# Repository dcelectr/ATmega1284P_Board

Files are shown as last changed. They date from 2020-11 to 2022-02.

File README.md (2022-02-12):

# ATmega1284P_Board
ATmega1284P board design is based on the [MightyCore](https://github.com/MCUdude/MightyCore).

The board features fairly easy to hand solder components, such as 0805 resistors, capacitors and LEDs, and it is breadboard friendly (100 mil spacing pin headers) with an orderly pin arrangement [(0 to 23, and A0 to A7)](https://camo.githubusercontent.com/318afd7cb36e720ea851fb34409d54c36701d0300eade1ba0faea744f00fc5db/68747470733a2f2f692e696d6775722e636f6d2f4b3334785a62342e6a7067) of the TQFP-44 package. 

The programming connector is a standard FTDI USB-UART adapter pin-out. The solder jumper (JP1) is closed by default. The board can be powered from the breadboard pin headers or the FTDI programming header. Using an FTDI TTL-232RG-VIP USB-UART adapter, the TTL voltage (Vttl) would be the same as the Vcc.

The Bill of Materials is also included (see file ATmega1284P.csv).

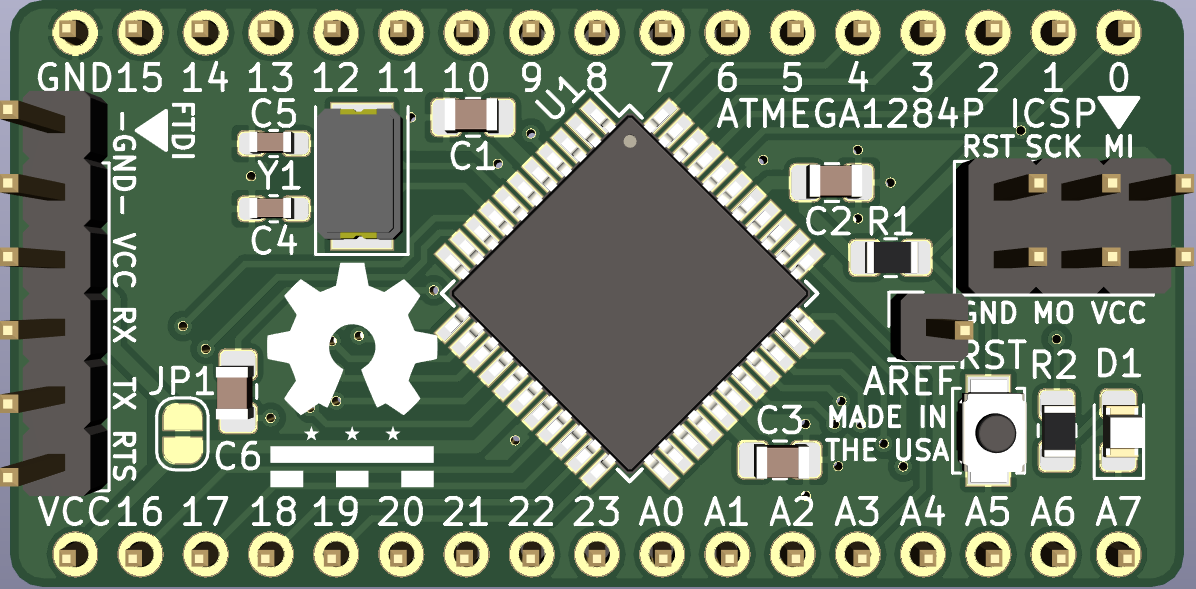
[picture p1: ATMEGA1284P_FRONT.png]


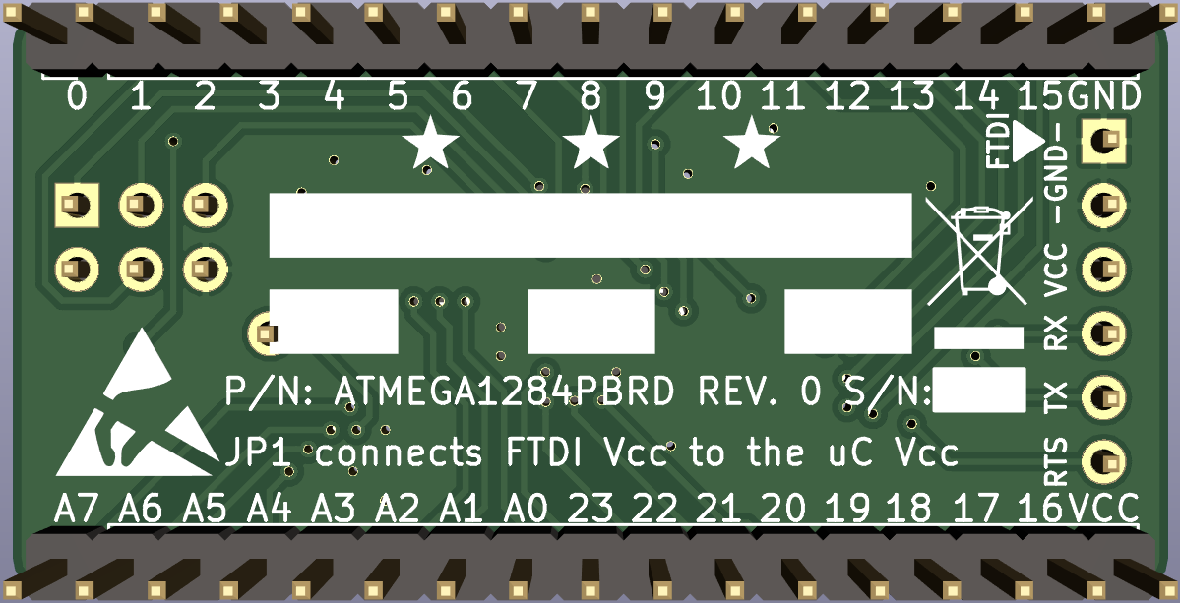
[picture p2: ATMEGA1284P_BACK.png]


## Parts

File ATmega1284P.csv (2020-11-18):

Reference | Quantity | Value | Footprint | Datasheet | P/N
C1 C2 C3 C6 | 4 | 0.1uF | Capacitor_SMD:C_0805_2012Metric_Pad1.18x1.45mm_HandSolder | ~ | C0805C104M3RACTU
C4 C5 | 2 | 22pF | Capacitor_SMD:C_0603_1608Metric_Pad1.08x0.95mm_HandSolder | ~ | C0603C220K3GACTU
D1 | 1 | LED | LED_SMD:LED_0805_2012Metric_Pad1.15x1.40mm_HandSolder | ~ | 150080VS75000
J1 | 1 | Conn_02x03_Odd_Even | Connector_PinHeader_2.54mm:PinHeader_2x03_P2.54mm_Vertical | ~
J2 | 1 | Conn_01x06_Male | Connector_PinHeader_2.54mm:PinHeader_1x06_P2.54mm_Vertical | ~
J3 J4 | 2 | Conn_01x17_Male | Connector_PinHeader_2.54mm:PinHeader_1x17_P2.54mm_Vertical | ~
J5 | 1 | Conn_01x01_Male | Connector_PinHeader_2.54mm:PinHeader_1x01_P2.54mm_Vertical | ~
JP1 | 1 | SolderJumper_2_Bridged | Jumper:SolderJumper-2_P1.3mm_Bridged_RoundedPad1.0x1.5mm | ~
R1 | 1 | 10K | Resistor_SMD:R_0805_2012Metric_Pad1.20x1.40mm_HandSolder | ~ | ERJ-6GEYJ103V
R2 | 1 | 1K | Resistor_SMD:R_0805_2012Metric_Pad1.20x1.40mm_HandSolder | ~ | ERJ-6GEYJ102V
SW1 | 1 | SW_Push | Button_Switch_SMD:SW_SPST_B3U-1000P | ~ | B3U-1000P
U1 | 1 | ATmega1284P-A | Package_QFP:TQFP-44_10x10mm_P0.8mm | http://ww1.microchip.com/downloads/en/DeviceDoc/Atmel-8272-8-bit-AVR-microcontroller-ATmega164A_PA-324A_PA-644A_PA-1284_P_datasheet.pdf | ATMEGA1284P-AU
Y1 | 1 | 16MHz | Crystal:Crystal_SMD_5032-2Pin_5.0x3.2mm | ~ | 7A-16.000MAAE-T

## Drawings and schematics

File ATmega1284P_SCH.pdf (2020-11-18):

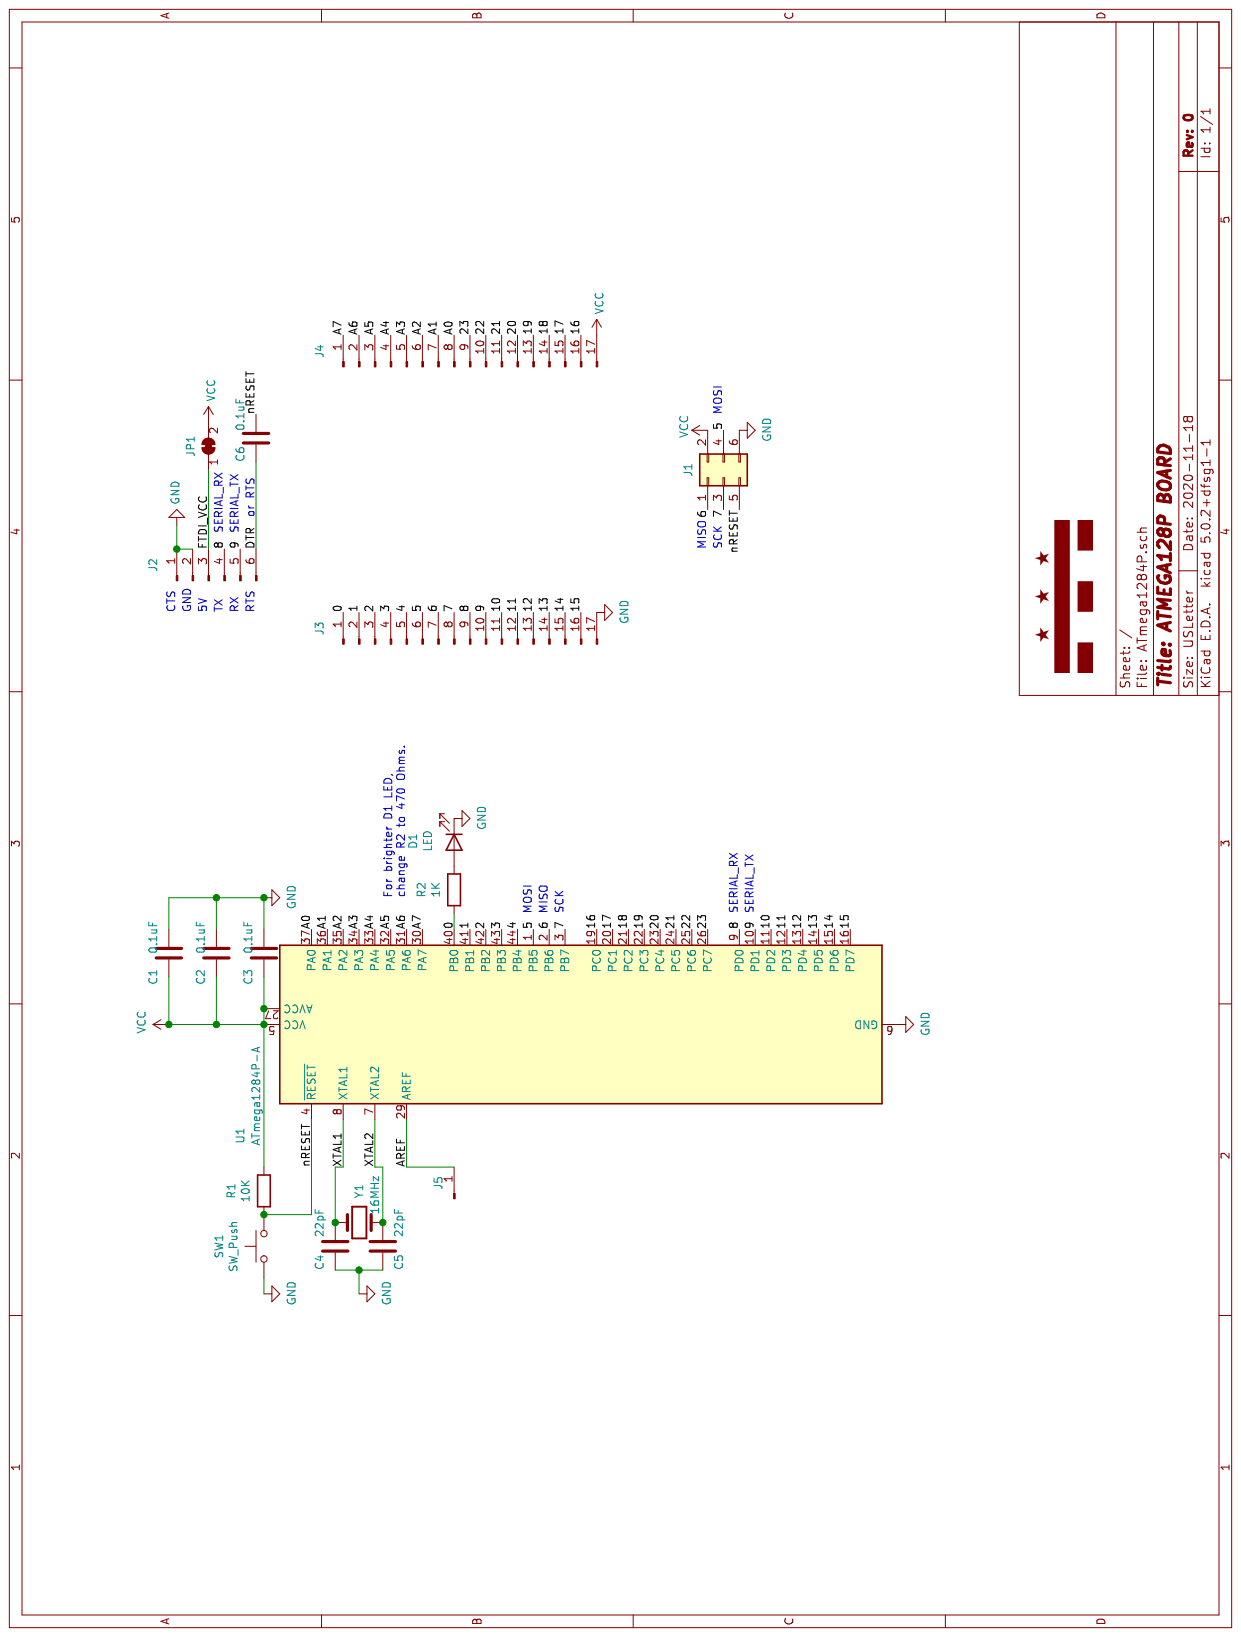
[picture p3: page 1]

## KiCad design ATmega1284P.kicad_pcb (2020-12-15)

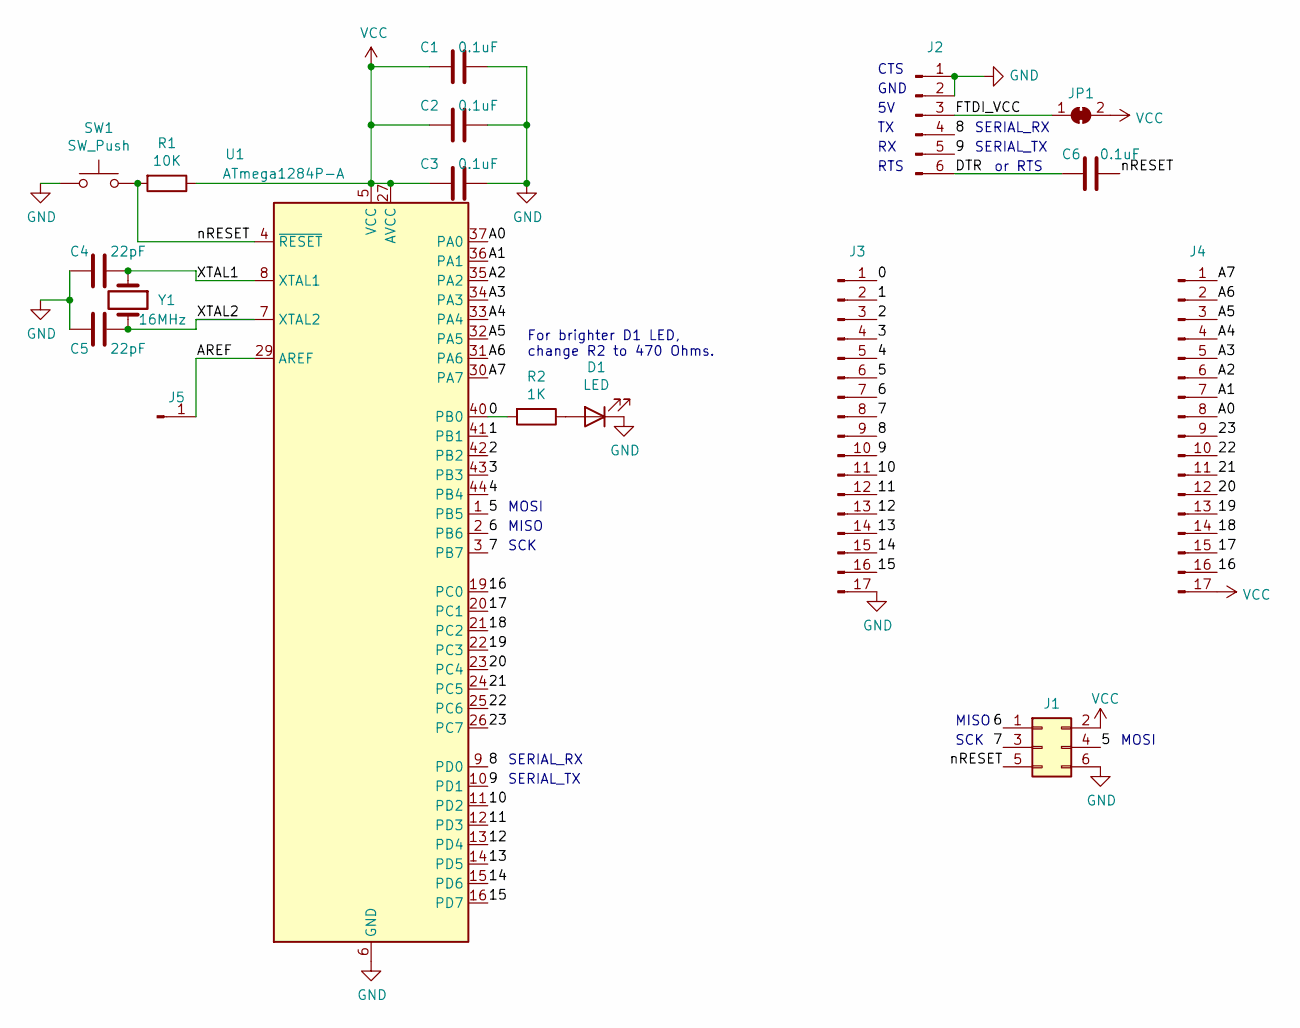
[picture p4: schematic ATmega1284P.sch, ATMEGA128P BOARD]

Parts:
C1, C2, C3, C6: 0.1uF; C_0805_2012Metric_Pad1.18x1.45mm_HandSolder
C4, C5: 22pF; C_0603_1608Metric_Pad1.08x0.95mm_HandSolder
D1: LED; LED_0805_2012Metric_Pad1.15x1.40mm_HandSolder
J1: Conn_02x03_Odd_Even; PinHeader_2x03_P2.54mm_Vertical
J2: Conn_01x06_Male; PinHeader_1x06_P2.54mm_Vertical
J3, J4: Conn_01x17_Male; PinHeader_1x17_P2.54mm_Vertical
J5: Conn_01x01_Male; PinHeader_1x01_P2.54mm_Vertical
JP1: SolderJumper_2_Bridged; SolderJumper-2_P1.3mm_Bridged_RoundedPad1.0x1.5mm
R1: 10K; R_0805_2012Metric_Pad1.20x1.40mm_HandSolder
R2: 1K; R_0805_2012Metric_Pad1.20x1.40mm_HandSolder
SW1: SW_Push; SW_SPST_B3U-1000P
U1: ATmega1284P-A; TQFP-44_10x10mm_P0.8mm
Y1: 16MHz; Crystal_SMD_5032-2Pin_5.0x3.2mm

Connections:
/0: J3.1, R2.2, U1.40 (PB0)
/1: J3.2, U1.41 (PB1)
/2: J3.3, U1.42 (PB2)
/3: J3.4, U1.43 (PB3)
/4: J3.5, U1.44 (PB4)
/5: J1.4, J3.6, U1.1 (PB5)
/6: J1.1, J3.7, U1.2 (PB6)
/7: J1.3, J3.8, U1.3 (PB7)
/8: J2.4, J3.9, U1.9 (PD0)
/9: J2.5, J3.10, U1.10 (PD1)
/10: J3.11, U1.11 (PD2)
/11: J3.12, U1.12 (PD3)
/12: J3.13, U1.13 (PD4)
/13: J3.14, U1.14 (PD5)
/14: J3.15, U1.15 (PD6)
/15: J3.16, U1.16 (PD7)
/16: J4.16, U1.19 (PC0)
/17: J4.15, U1.20 (PC1)
/18: J4.14, U1.21 (PC2)
/19: J4.13, U1.22 (PC3)
/20: J4.12, U1.23 (PC4)
/21: J4.11, U1.24 (PC5)
/22: J4.10, U1.25 (PC6)
/23: J4.9, U1.26 (PC7)
/A0: J4.8, U1.37 (PA0)
/A1: J4.7, U1.36 (PA1)
/A2: J4.6, U1.35 (PA2)
/A3: J4.5, U1.34 (PA3)
/A4: J4.4, U1.33 (PA4)
/A5: J4.3, U1.32 (PA5)
/A6: J4.2, U1.31 (PA6)
/A7: J4.1, U1.30 (PA7)
/AREF: J5.1, U1.29 (AREF)
/DTR: C6.2, J2.6
/FTDI_VCC: J2.3, JP1.1 (A)
/XTAL1: C4.1, U1.8 (XTAL1), Y1.1
/XTAL2: C5.1, U1.7 (XTAL2), Y1.2
/nRESET: C6.1, J1.5, R1.2, SW1.2, U1.4 (~RESET)
GND: C1.1, C2.1, C3.1, C4.2, C5.2, D1.1 (K), J1.6, J2.1, J2.2, J3.17, SW1.1, U1.6 (GND), U1.18 (GND), U1.28 (GND), U1.39 (GND)
unnamed: D1.2 (A), R2.1
VCC: C1.2, C2.2, C3.2, J1.2, J4.17, JP1.2 (B), R1.1, U1.5 (VCC), U1.17 (VCC), U1.27 (AVCC), U1.38 (VCC)

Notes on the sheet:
SERIAL_RX
SERIAL_TX
MOSI
MISO
SCK
or RTS
CTS
GND
RTS
For brighter D1 LED, change R2 to 470 Ohms.

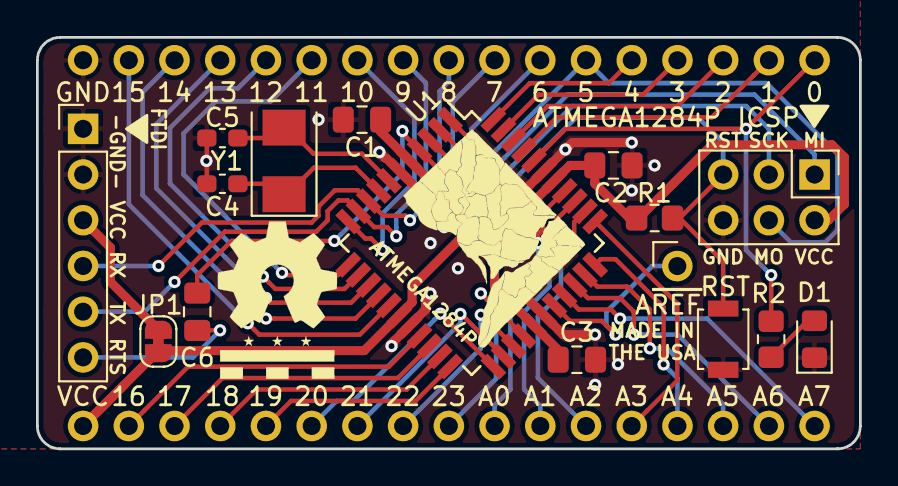
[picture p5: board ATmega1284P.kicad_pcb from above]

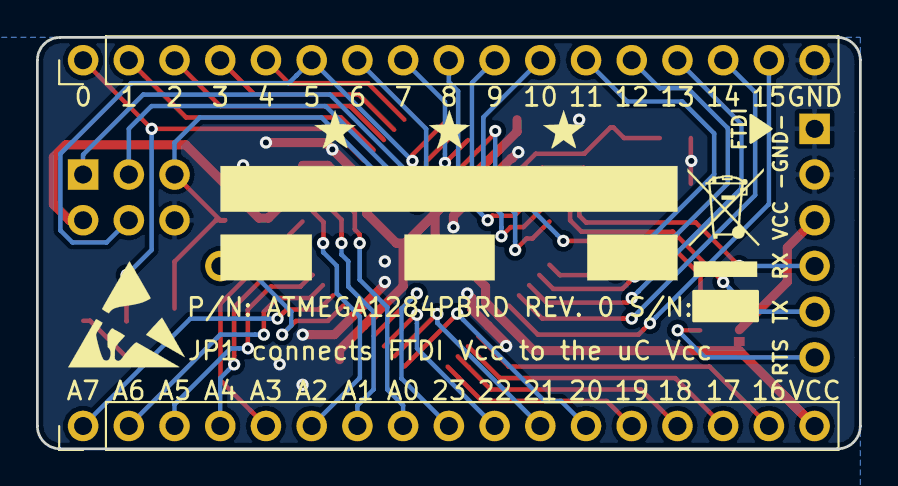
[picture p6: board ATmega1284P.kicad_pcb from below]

Board: 2 copper layers, 45.7 x 22.9 mm, 18 parts (2 on the bottom side), 41 nets.

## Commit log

2020-11-18 KiCad Files
    [ATmega1284P.csv, ATmega1284P.kicad_pcb, ATmega1284P.sch]
2020-11-18 KiCad Files
    Added PDF schematic
2020-11-18 KiCad Files
    Aligned AREF pin to be 0.1" offset from the ICSP
    [ATmega1284P.kicad_pcb]
2020-12-15 Added silkscreen under the ATmega1284P chip
    Added the District of Columbia map shape (silkscreen) under the ATmega1284P chip.
    [ATmega1284P.kicad_pcb]
